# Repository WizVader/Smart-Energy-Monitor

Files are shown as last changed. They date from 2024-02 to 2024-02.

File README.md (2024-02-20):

Header Image

# ELECTENG 209 Project Repository

For the final implementation. Head over to Basic -> Final Implementation

## 🎯 Design Specifications

| Parameter | Value |
| --- | --- |
| Source Voltage | 14 VRMS ± 10% |
| Source Frequency | 500 Hz ± 2% |
| Load Range | 2.5 VA to 7.5 VA |
| Load Power Factor | 0.6 to 0.99 |
| Measurement Accuracy | ±5% of full-scale reading |
| ADC Conversion Rate | 10 kHz or slower |
| MCU System Clock | 2 MHz |
| LCD Display Information | Voltage (Vrms), Current (mApeak), Power (W) |
| LCD Scroll Rate | 1 s |
| UART Specifications | 9600 Baud 8N1 with No Parity |
| Information Transferred Via UART | Voltage, Peak Current, Power and Energy |
| BLE Functionality | Optional |
| PCB Size | 20000 mm² |
| PCB Technology | Double Layer with PTH |
| Device Technology | TH or SMT |

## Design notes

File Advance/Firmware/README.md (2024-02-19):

Header Image

# Firmware for Smart Energy Monitor

This folder should contain your Atmel Studio project with your firmware.

> **Note**  
> Make sure to use separate modules, eg `uart.c`, `adc.c`, `timer1.c`, `display.c`, `energycalculations.c`, etc.

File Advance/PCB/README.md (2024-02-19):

Header Image

# PCB for Smart Energy Monitor

This folder should contain your Altium Designer files for your PCB design.

> **Warning**  
> Altium files are *binary* files rather than *text* files, meaning Git cannot easily track changes (at least not in a human-readable manner).
> 
> For your PCB work in Altium, you should take one of the following approaches:
> - if using branches, maintain a single Altium-specific branch until the design is complete;
> - if not using branches, assign one team member to do the schematic and another to the PCB afterwards; or
> - for the **safest option**, work on your Altium project outside of your Git repository and only commit it once it is finished.

> **Warning**  
> Merge conflicts betweeen binary files are **impossible to resolve** (without overwriting all changes from one version with the other version).
>
> This means that **it is imperative** that **anyone** who works on the Altium schematic/PCB artwork always:
> 1. `fetch`es and `pull`s any new upstream changes **before** beginning any work, and
> 2. `commit`s and `push`es their latest changes at the end of **every session**.
> 
> This is the only way to completely avoid merge conflicts.

> **Note**  
> Ask a TA for help if either of the two warnings above do not make sense.

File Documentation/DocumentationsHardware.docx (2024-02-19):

# Hardware Design Choices

### AC Load

Originally, our shunt resistor value was 0.5645Ω

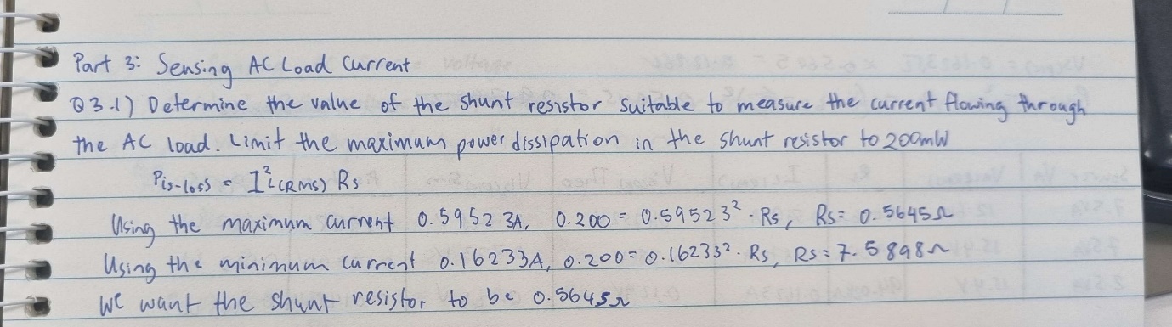
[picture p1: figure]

Figure 1: Original Calculation for Shunt Resistor

However, we cannot get this specific value using E12 values. The closest we can get to 0.5645Ω is two 1Ω resistors in parallel.

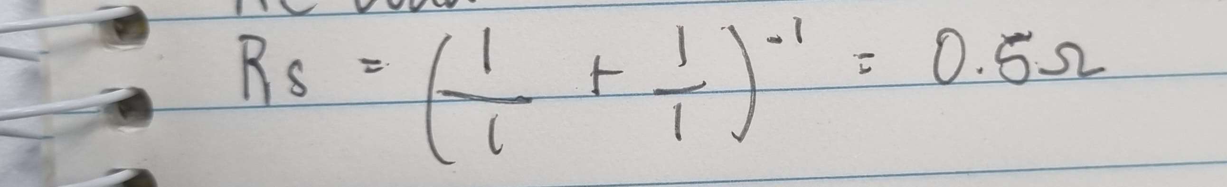
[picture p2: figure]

Figure 2: Calculation for new Shunt Resistor

### DC Regulator and Power LED

We had chosen our Rreg1 value to be 22 ohms because it was the closest E12 value to 20 ohms. However, Duleepa recommended that we should we have two resistors in parallel because the resistor has low power rating so we might burn our components. We decided to go ahead with his feedback because our circuit will have better heat distribution leading to a longer lifetime.
We found that putting 27Ω and 82Ω resistors in parallel was the closest we can get to 20Ω.

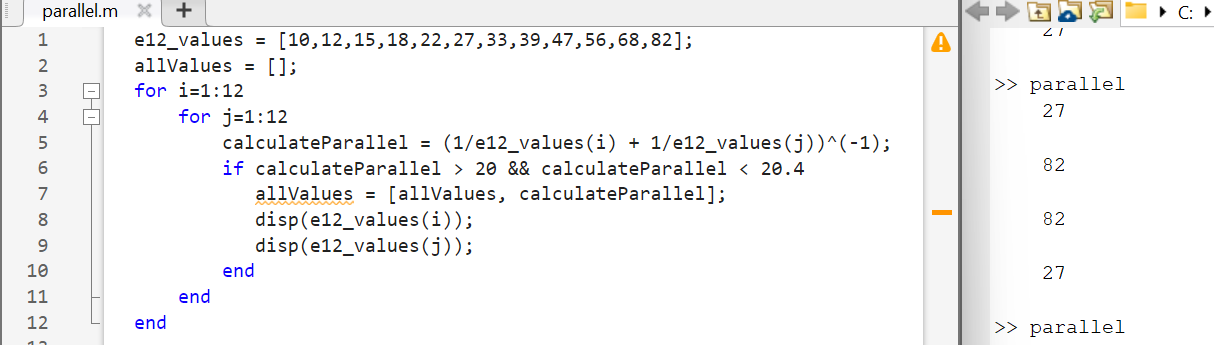
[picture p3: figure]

Figure 3: Calculation for Regulator Resistors in parallel

We chose a 48uF and 10uF electrolytic capacitors because it is good for low frequency decoupling. We used 100nF ceramic capacitors for high frequency decoupling. However, when we acquired the ceramic capacitors from the components store, we measured the voltage limit, and it was 16V. This is too low for our requirements, so this is not implemented in our final PCB.

### Offset Generator

We decided to use a buffer to maintain a 2.1V offset. Using E12, the closest voltage we could get was 2.0625V using a 33kΩ and 47kΩ voltage divider. We also put a 100nF ceramic capacitor for high frequency decoupling.

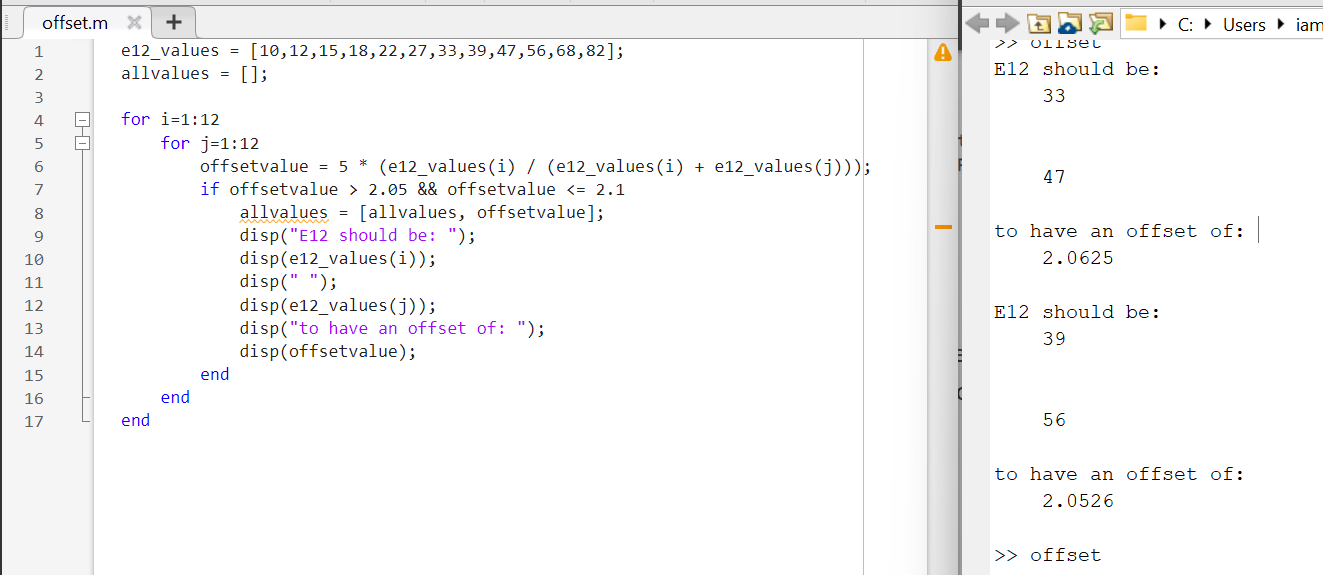
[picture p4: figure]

Figure 4: Calculation for Offset Resistor values

### Voltage Sensing Amplifier

We wanted to have no common ground voltage in our voltage sensing. From our Lab 2 calculation, this meant that R1/R2 = R3/R4. We chose to have all resistor values to be 100k.

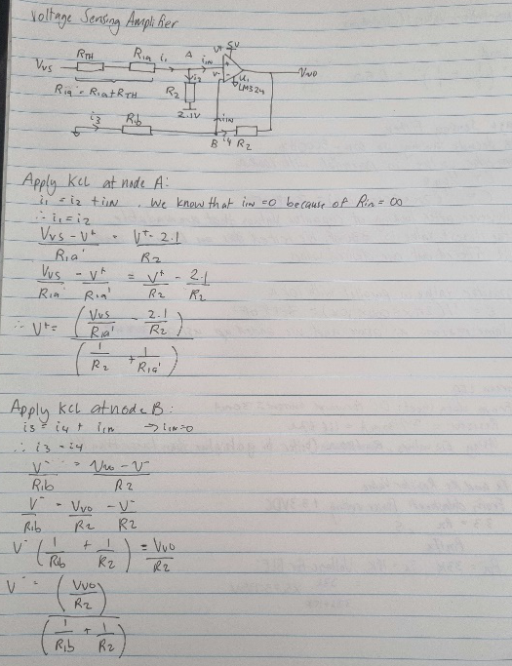
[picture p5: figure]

Figure 5: Resistor Values for Voltage Sensing Part 1

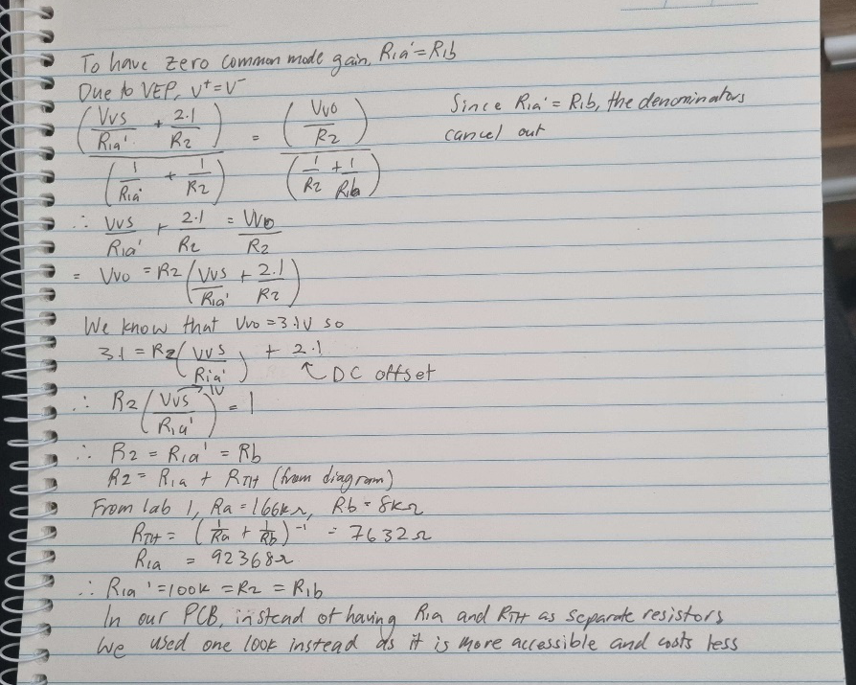
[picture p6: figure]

Figure 6: Resistor Values for Voltage Sensing Part 2

For our second order filter, we chose a breakpoint frequency of 5kHz. When looking at our LTSpice simulation, the magnitude starts to decrease below 500Hz. Since our desired frequency is 500Hz, we do not want our signal to be filtered at 500Hz. Also, the signal may not exactly be 500Hz so we want to capture ranges slightly bigger or smaller than 500Hz. These capacitor values also apply to the Current Sensing Amplifier.

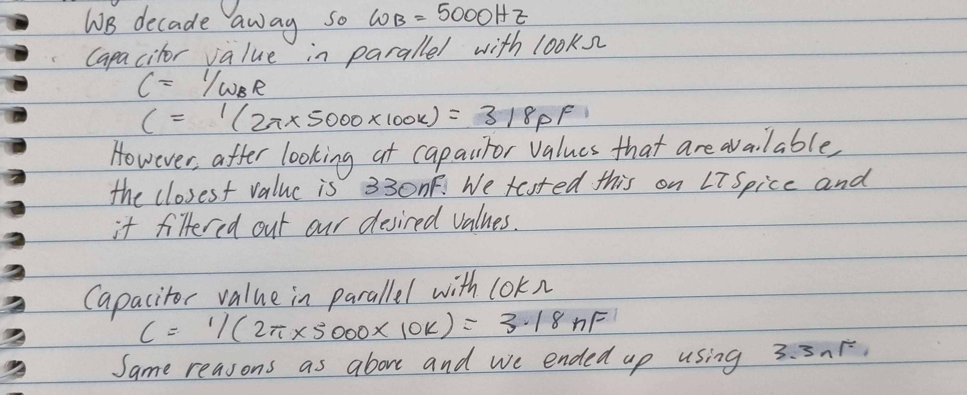
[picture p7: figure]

Figure 7: Capacitor Values for Voltage and Current Sensing Filtration

### Current Sensing Amplifier

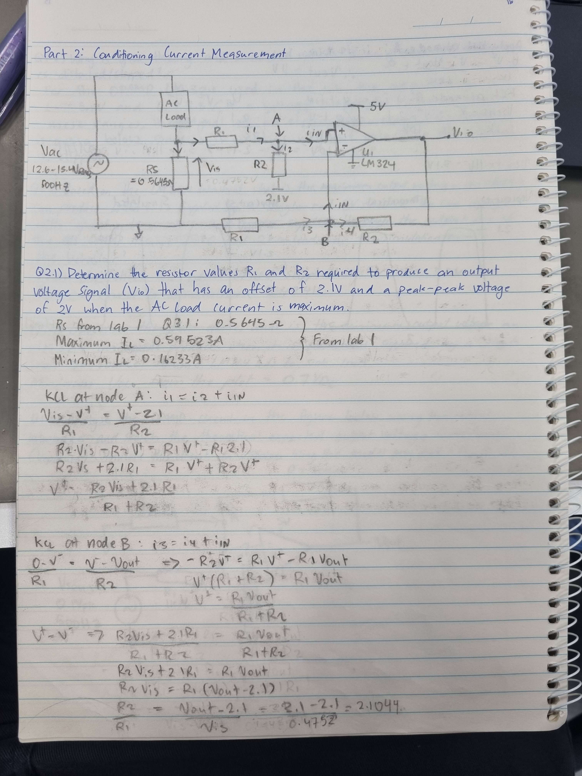
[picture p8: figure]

Figure 8: Calculating Current Sensing Resistors

We know that R2 = 2.1044*R1. Using E12 values, we chose R1 = 47k and R2 = 100k

### Comparator (Zero Crossing Detector)

Initially, hysteresis was the choice because we only had a low pass filter. Once we used a cascading low pass filter, we tested the circuit without hysteresis and found that it made no difference. So, to save us resources and time, we decided to not implement hysteresis and use a normal comparator.

We removed the potential implementation of a comparator for the current sensing due to being limited to only 4 OPAMP in the IC.

### Test LEDs

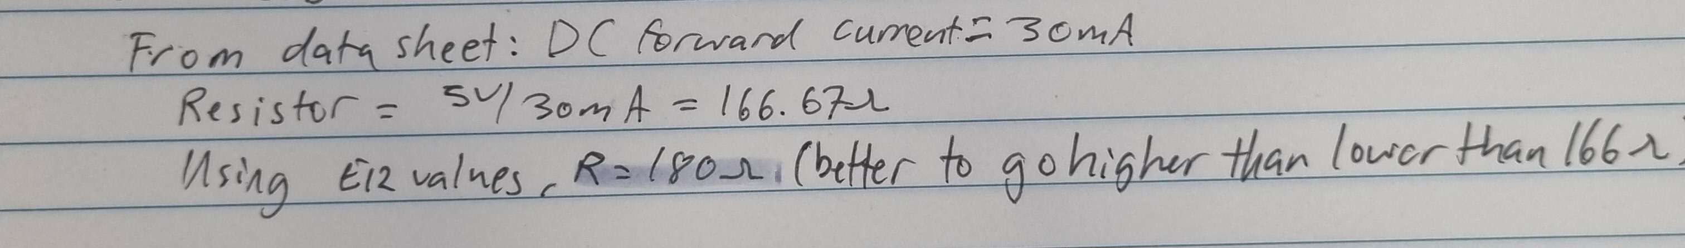
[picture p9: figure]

Figure 9: Resistor value for LEDs

### BLE Header

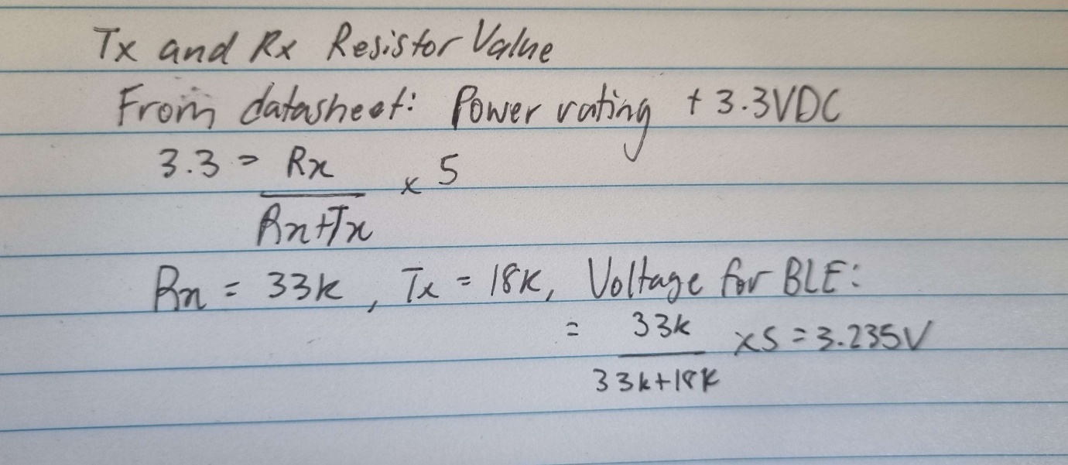
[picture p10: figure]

Figure 10: Resistor values for Tx and Rx for the BLE module

### Decoupling Capacitors

The purpose of these decoupling capacitors is to provide 5V if at any point the power supply was not able to. We chose 100nF because it can respond quickly to voltage fluctuations if the voltage drops below 5V.

### PCB

We tried testing our regulator after soldering it onto the PCB. The regulator smoked up once we connected the input of the PSU to our PCB. So initially we thought there was a problem with the barrel jack or our PCB traces. We only soldered the resistors to our input voltage and checked the output of that to verify our PCB. Turns out that it works properly, and the problem is with the regulator. It is mostly something with the ratings of the regulator. So, we have to look into it and change our regulator resistances or the regulator itself.

Team 09: Charan, Sai Kiran, Kristelle, Pratham

ELECTENG/COMPSYS209

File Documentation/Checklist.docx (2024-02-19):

Checklist:

- Display RMS Voltage on terminal and/or 7 segment display

- Display Peak Current on terminal and/or 7 segment display

- Display Power on terminal and/or 7 segment display

- Able to produce appropriate analog signals at the input of the ADCs

- Clear schematic and good PCB layout

- Modular and Readable code with comments

- Ltspice model is clear and has appropriate device values

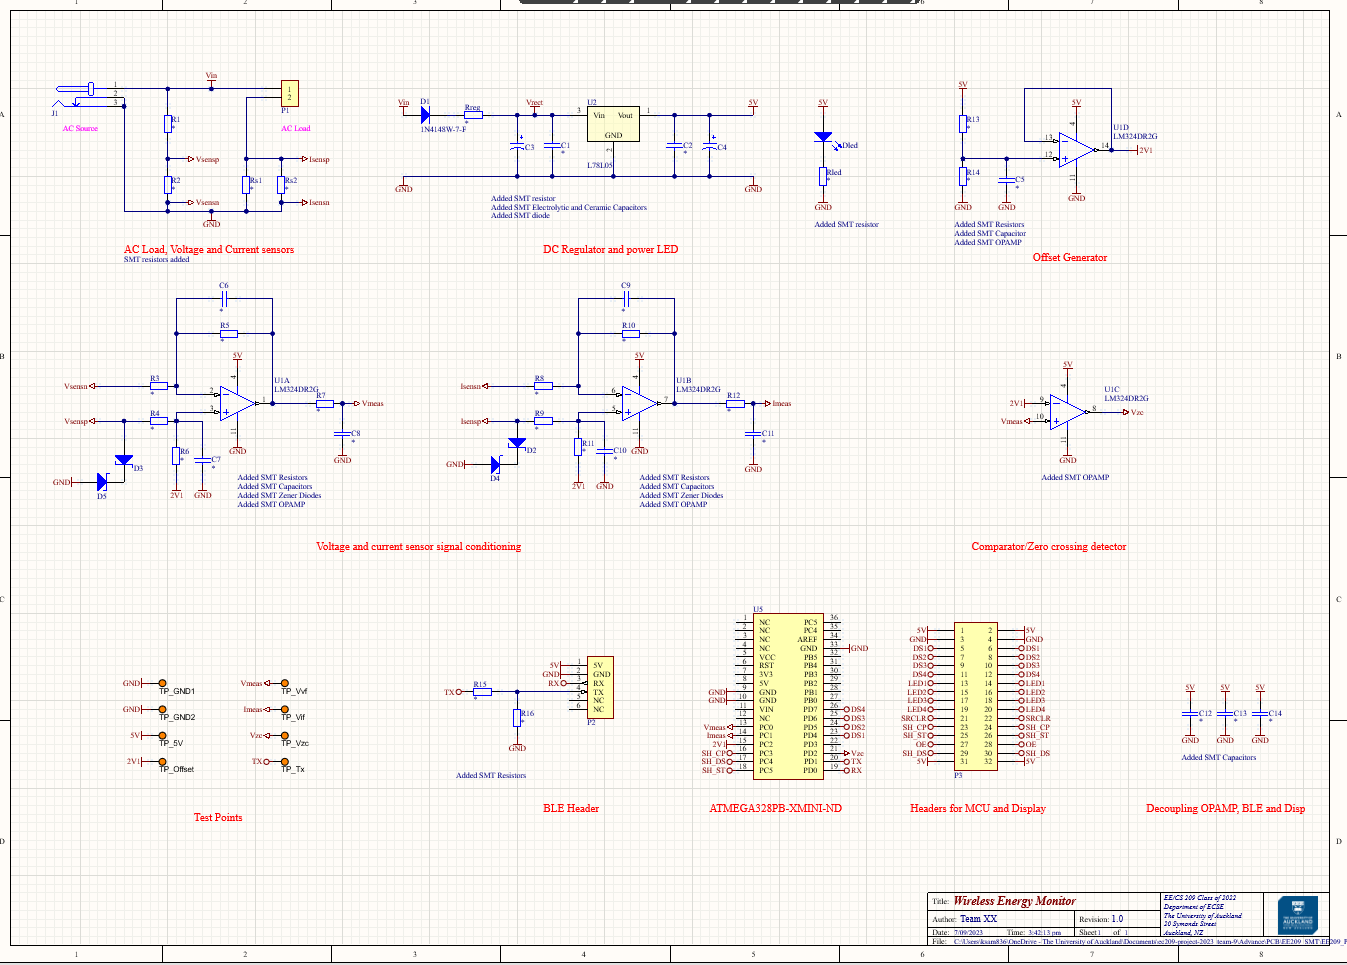
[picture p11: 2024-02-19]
Documentation/Capture.PNG

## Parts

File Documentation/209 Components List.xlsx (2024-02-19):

Component (Altium): | Value: | Value (Resistance) | Quantity | Component (Altium): | Value | Type | Value (Capacitor) | Quantity | Component | Quantity
R1 | 56k | 1 | 2 | C1 | 100n | Ceramic | 330p | 4 | 4.7V Zener Diodes | 4
R2 | 2.7k | 27 | 1 | C2 | 100n | Ceramic | 3.3n | 2 | Diode | 1
Rs1 | 1 | 82 | 1 | C3 | 47u | Electrolytic | 100n | 9 | LED | 1
Rs2 | 1 | 180 | 4 | C4 | 10u | Electrolytic | 10u | 1 | OPAMP | 1
Rreg1 | 27 | 2.7k | 1 | C5 | 100n | Ceramic | 47u | 1 | Regulator | 1
Rreg2 | 82 | 10k | 2 | C6 | 330p | Ceramic |  |  | Test Points | 8
R3 | 100k | 18k | 1 | C7 | 330p | Ceramic
R4 | 100k | 33k | 2 | C8 | 3.3n | Ceramic
R5 | 100k | 47k | 3 | C9 | 330p | Ceramic
R6 | 100k | 56k | 1 | C10 | 330p | Ceramic
R7 | 10k | 100k | 6 | C11 | 3.3n | Ceramic
R8 | 47k |  |  | C12 | 100n | Ceramic
R9 | 47k |  |  | C13 | 100n | Ceramic
R10 | 100k | SMD Values Conversion |  | C14 | 100n | Ceramic
R11 | 100k | 1r00 | 1 | C15 | 100n | Ceramic
R12 | 10k | 22r0 | 22 | C16 | 100n | Ceramic
R13 | 47k |  | 27 | C17 | 100n | Ceramic
R14 | 33k |  | 82
R15 | 33k | 1800 | 180
R16 | 18k | 2701 | 2.7k
Rdb1 | 180 | 103 | 10k
Rdb2 | 180 |  | 18k
Rdb3 | 180 | 3302 | 33k
Rdled | 180 |  | 47k
 |  | 563 | 56k
 |  | 104 | 100k

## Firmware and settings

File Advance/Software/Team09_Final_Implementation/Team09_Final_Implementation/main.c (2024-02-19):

/*
* Team_09_Firmware.c
*
* Created: 14-08-2023 12:27:34
* Author: Charanjeet, Sai Kiran, Kristelle, Pratham
*/

#define F_CPU 2000000UL

// Adding necessary include statements
#include <avr/io.h>
#include <stdio.h>
#include <avr/interrupt.h>
#include <util/delay.h>
#include <math.h>
// Header includes
#include "uart.h"
#include "Display.h"
#include "ADC.h"
#include "Timer0.h"

//Creating a stream variable
static FILE usart_stdout = FDEV_SETUP_STREAM(uart_printf, NULL, _FDEV_SETUP_WRITE);

// Initialise variables and arrays needed for ADC0 and ADC1
float ADC0[60];
float ADC1[60];
uint16_t rawADC0[60];
uint16_t rawADC1[60];

// Initialise RMS variables, Peak Current, and Power
float VrmsValue = 0;
float IrmsValue = 0;
float PeakCurrent = 0;
float power = 0;
uint8_t PowerInteger = 0;

// Initialise variables that are used for printing purposes
uint8_t VrmsInteger = 0;
uint8_t VrmsDecimal = 0;
uint16_t IrmsDecimal = 0;
uint16_t PeakCurrentDecimal = 0;
uint16_t PowerDecimal = 0;

// Initialise check and counter values
volatile uint8_t counter = 0;
volatile uint8_t checker = 0;

//Initialise amount of samples we want to take
uint8_t samples = 60;

// Set calculated inductive reactance value
float inductive_reactance = 12.56637;

// Initialise variables used for display
uint8_t decimalPos = -1;
int four_digit = 0;


int main(void)
{
	//Binding the stream variable to stdout
	stdout = &usart_stdout;
	
	// Set ports used for debugging
	DDRB |= (1<<DDB5);
	DDRD &= ~(1<<DDD2);
	
	//initialising display and timer
	init_display();
	timer0_init();
	
	// Initialise UART 
	usart_init(12); // UBRR set to 12 for 9600 baud rate
	
	// Initialise INT0 to trigger during rising edge
	EICRA |= (1<<ISC01) | (1<<ISC00);
	
	// Enable global interrupts
	sei();
	
	while (1) {
		
		// Poll until all samples are taken for voltage and current sensing
		while (checker == 0) {
			// Start ADC conversions
			adc_conversion_trigger();
		}
		
		
		// Start processing ADC values after all samples are taken
		if (checker == 1) {
			
			// Process each sample
			for(int i = 0; i<samples; i++){
				// Converted to mV
				ADC0[i] = adc_process_voltage(rawADC0[i]);
				// Converted to mA
				ADC1[i] = adc_process_current(rawADC1[i]);
			}
			
			
			// Apply Riemann Sum to acquire RMS value
			VrmsValue = calculate_rms(ADC0, samples,0); // in V 
			IrmsValue = calculate_rms(ADC1, samples,1); // in mA
			
			// Convert IrmsValue to PeakCurrent
			PeakCurrent = IrmsValue * sqrt(2);
			
			// Calculate power in mW using Vrms, Irms, and power factor
			power = calculate_power(VrmsValue, IrmsValue);
			
			// Separate float values into integers for 4 digit printing to match display
			VrmsInteger = (int) VrmsValue; // Get integers
			VrmsDecimal = (int)(VrmsValue*100) % 100; // Get 2 dp
			PeakCurrentDecimal = (int)(PeakCurrent*1000); // Get 4 dp
			PowerInteger = (int)(power); // Get integers
			PowerDecimal = (int)(power*1000) % 1000; // Get 3 dp
			
			// Display "VOLT"
			displayVoltage();
			
			_delay_ms(1000); // Delay 1s for readability
			
			// Sends the correctly formatted number to the display
			int toSend = float_to_integer(VrmsValue);
			seperate_and_load_characters(toSend, decimalPos);
			
			// Prints the RMS Voltage
			printf("RMS Voltage is: %d.%dV\r\n", VrmsInteger,VrmsDecimal);
			
			_delay_ms(1000); // Delay 1s for readability
			
			// Displays "CRNT"
			displayCurrent(); 
			
			_delay_ms(1000); // Delay 1s for readability
			
			// Sends the correctly formatted number to the display
			toSend = float_to_integer(PeakCurrent);
			seperate_and_load_characters(toSend,decimalPos);
			
			// Prints Peak Current
			printf("Peak Current is: %dmA\r\n", PeakCurrentDecimal);
			
			_delay_ms(1000); // Delay 1s for readability
			
			
			// Displays "POW"
			displayPower();
			
			_delay_ms(1000); // Delay 1s for readability
			
			// Sends the correctly formatted number to the display
			toSend = float_to_integer(power);
			seperate_and_load_characters(toSend,decimalPos);
			
			// Prints the Power 
			printf("Power is: %d.%dW\r\r\n", PowerInteger, PowerDecimal);
			
			_delay_ms(1000); // Delay 1s for readability
			
			// Set checker to 0 again to start taking samples
			checker = 0;
		}
	}
	
}

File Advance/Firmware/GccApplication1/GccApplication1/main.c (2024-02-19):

/*
 * Team_09_Firmware.c
 *
 * Created: 14-08-2023 12:27:34
 * Author: Charanjeet, Sai Kiran, Kristelle, Pratham
 */ 

#define F_CPU 2000000UL

// Adding necessary include statements
#include <avr/io.h>
#include <stdio.h>
#include <stdlib.h>
#include <avr/interrupt.h>
#include <util/delay.h>
#include "uart.h"
#include "Display.h"
#include "ADC.h"
#include <math.h>



//Creating a stream variable
static FILE usart_stdout = FDEV_SETUP_STREAM(uart_printf, NULL, _FDEV_SETUP_WRITE);

// Defining values for RMS Voltage, Peak Current and Power Consumption to be transmitted.
//#define RMSVoltage 14.5
uint32_t RMSVoltage = 0;
//#define RMSVoltage 12.5
#define PeakCurrent 12.5
//uint32_t power = 0;
uint8_t decimalPos = -1;
int four_digit = 0;



// Initialise arrays for ADC0 and ADC1
uint16_t ADC0[40];
uint16_t ADC1[40];
// Initialise arrays for linear approximation values 
uint16_t voltageLinearApprox[40];
uint16_t currentLinearAprrox[40];
uint32_t powerArray[40];


uint32_t RMSVoltageCalc(uint16_t ADC0[40], int nSamples) {
	
	// Calculate the squared voltage
	// sum all voltage values
	// Calculate the mean
	// Square the mean voltage value
	
	uint32_t sumVoltage = 0;
	for (int i = 0; i < nSamples; i++) {
		
		// Square the voltage values
		//sumVoltage += (uint32_t)ADC0[i] * (uint32_t)ADC0[i];	
		ADC0[i]/1000;	
		sumVoltage += pow(ADC0[i], 2);
		sumVoltage = abs(sumVoltage);
	}
	
	//double step = 1 / (double)nSamples;
			
	// Calculate the mean
	uint32_t meanVoltage = sumVoltage / nSamples;
		
	// Square the mean voltage and return it
	return sqrt(meanVoltage);
}


int isInteger(float value) {
	return value == (int)value;
}

uint32_t sendWholeNumber(float num, int dec) {
	return (int)num*(pow(10,(dec+1)));
	
}


int findDecimalPoint(float num) {
	int position = 0;
	float tempNum = num;
	
	while(tempNum - (int)tempNum != 0) {
		tempNum *= 10;
		position++;
	}
	return position;
}


int float_to_integer(float toDisplay){
	if((int)(toDisplay) == 0){
		decimalPos = -1;
		four_digit = (int)(toDisplay*10000);
	}	
	else if (toDisplay < 10 && toDisplay > 0){
		decimalPos = 3;
		four_digit = (int)(toDisplay*1000);
	}
	else if (toDisplay <100 && toDisplay>= 10){
		decimalPos = 2;
		four_digit = (int)(toDisplay*100);
	}
	else if (toDisplay < 1000 && toDisplay >= 100){
		decimalPos = 1;
		four_digit = (int) (toDisplay*10);
	}
	else{
		four_digit = (int)(toDisplay);
		decimalPos = -1;
	}
	
	return four_digit;
}
	


int main(void)
{
    //Binding the stream variable to stdout
    stdout = &usart_stdout;
    
    // Using the calculated ubrr value of 12 to initialise uart 
    usart_init(12);
	
	init_display();
	timer0_init();
		
	// Initialise the ADC
	adc_init();

	sei();
		
     while (1) {
 		// Take 80 samples, alternating between ADC0 and ADC1
 		for(int i = 0; i<40; i++){
 
 			// Read from ADC0
 			uint16_t readADC0 = adc_read(0);
 			// Convert to mv
 			uint16_t ADC0_mv = adc_process_voltage(readADC0);
 			// Add to array
 			ADC0[i] = ADC0_mv;
			  			
 			// Read from ADC1
 			uint16_t readADC1 = adc_read(1);
 			// Convert to mA
			uint16_t ADC1_mA = adc_process_current(readADC1);
			// Add to array
			//ADC1[i] = ADC1_mA;
			ADC1[i] = readADC1;
 		}

		for (int i = 0; i < 40; i++) {
			
			printf("%d", ADC1[i]);
			printf("\r\n");
		}
		
		RMSVoltage = RMSVoltageCalc(ADC0[40], 40);
		
		
		// Use the processed voltage and current values and take linear approximation between two points
		for(int k = 0; k<40; k++){
			
			// For voltage approximation, last value is not approximated
			if(k<39){
				voltageLinearApprox[k] = (ADC0[k] + ADC0[k+1])/2;
			}
			
			// For current approximation, first value is not approximated
			if(k>0){
				currentLinearAprrox[k] = (ADC1[k-1] + ADC1[k])/2;
			}
		}
	
// 		// Power Calculation
// 		power = powerCalculation(ADC0, ADC1, voltageLinearApprox, currentLinearAprrox);
// 		printf("Power is: %lu \r\n", power);
		
		//seperate_and_load_characters(power, 3);
		
        // Printing the RMS Voltage while separating and printing each number of the double value
        printf("RMS Voltage is: %d%d.%d\r\n", (int)RMSVoltage/10 , (int)RMSVoltage%10, (int)(RMSVoltage*10)%10 );
        		
		//float current = 114.5;
		
		//uint32_t intValue = (uint32_t)(current * 100);	
		
		//int decimalPos = findDecimalPoint(current);
		//printf("NUMBER: %d\r\n", sendWholeNumber(current));
		
		//printf("float_to_int is %d, dp id %d\r\n", toSend, decimalPos);
		
		// Temporary Global variables
		float voltage = 14.30;
		float current = 130.15;
		float power = 2.542;
				
				
		displayCurrent();
		
		 _delay_ms(1000);
		 
		 
		int toSend = float_to_integer(current);
		seperate_and_load_characters(toSend, decimalPos);	
		
		printf("Decimal position %d expected 1\r\n", decimalPos);
		
		_delay_ms(1000);	
		
		displayVoltage();
		
		
		_delay_ms(1000);
		
		 toSend = float_to_integer(voltage);
		seperate_and_load_characters(toSend, decimalPos);	
		printf("Decimal position %d expected 2\r\n", decimalPos); 
		
		_delay_ms(1000);
		
		displayPower();
		
		_delay_ms(1000);
		
		 toSend = float_to_integer(power);
		seperate_and_load_characters(toSend, decimalPos);
		printf("Decimal position %d expected 3\r\n", decimalPos);
		
        // delay of 1s
        _delay_ms(1000);
        
        //printing the Peak Current
        printf("Peak Current is: %d\r\n", PeakCurrent);
        // delay of 1s
        _delay_ms(1000);
        
        // Printing the Power while separating and printing each number of the double value
        //printf("Power is: %d.%d%d\r\n", (int)Power%10, (int)(Power*10)%10, (int)(Power*100)%10);
        
        // delay of 1s
        _delay_ms(1000);
        
        //printing a blank line before the next iteration
        printf("\r\n");
    }
 
}
